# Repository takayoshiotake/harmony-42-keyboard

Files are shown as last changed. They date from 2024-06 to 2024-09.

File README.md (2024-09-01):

# Harmony 42

[][cc-by-sa]
[][freecad]
[][inkscape]
[][kicad]
[][vial]

A 42-key keyboard.

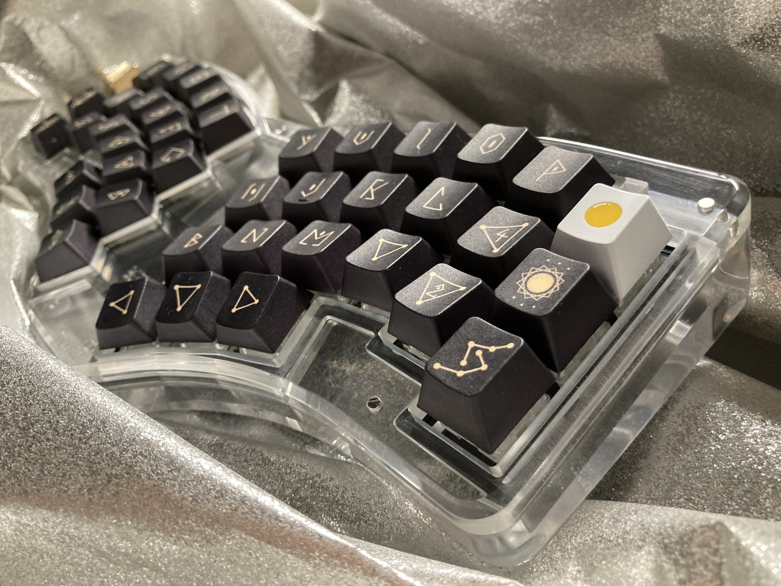
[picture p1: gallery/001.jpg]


- Switch: TTC Frozen V2
- Keycap: StarryPoem + HIBI Artisan

## Concept



## Layout

v0.1.0

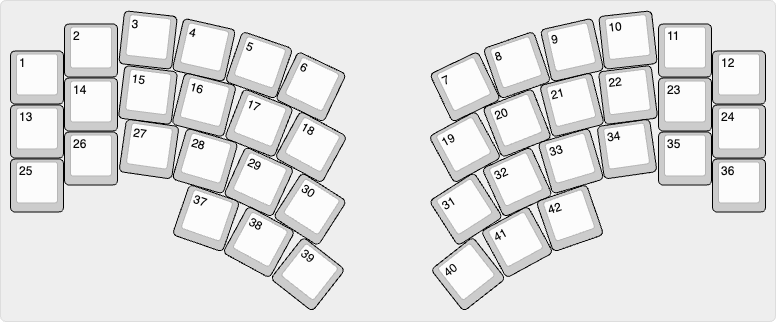
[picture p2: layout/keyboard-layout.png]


- width: 14u
- depth: <6u

Made with Python script: 📁 [editor](layout/editor)

- 📄 [locations.csv](layout/locations.csv)
- 📄 [keyboard-layout.rawdata.json](layout/keyboard-layout.rawdata.json)

## BOM

| Material | QTY | Note |
|-|-:|-|
| Harmony 42 PCB | 1 | [Schematic-and-PCB](#schematic-and-pcb) |
| MCU 16 PCB | 1 | [Schematic-and-PCB](#schematic-and-pcb) |
| Harmony 42 Case | 1 | PMMA CNC, [Mechanics](#mechanics) |
| Harmony 42 Gasket | 1 | PORON 2mm, [Mechanics](#mechanics) |
| Harmony 42 Plate | 1 | Acrylic 1.5mm, [Mechanics](#mechanics) |
| FFC | 1 | 16 ciruits, 0.50mm pitch, Type D (opposite sides), >50mm length |
| Screw: M2 x 4mm | 5 | |

## Schematic and PCB

schematic svg

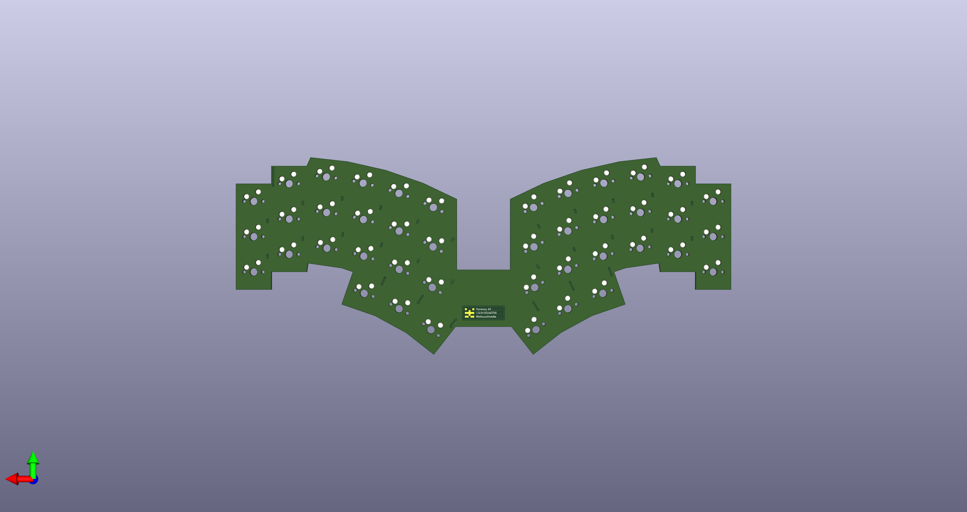
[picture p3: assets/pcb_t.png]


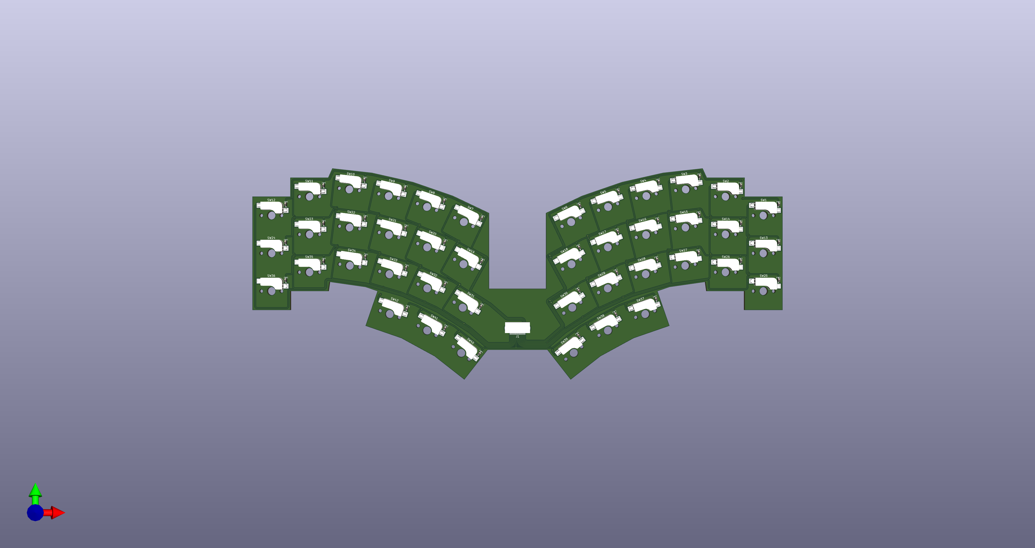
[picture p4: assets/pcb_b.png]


schematic svg

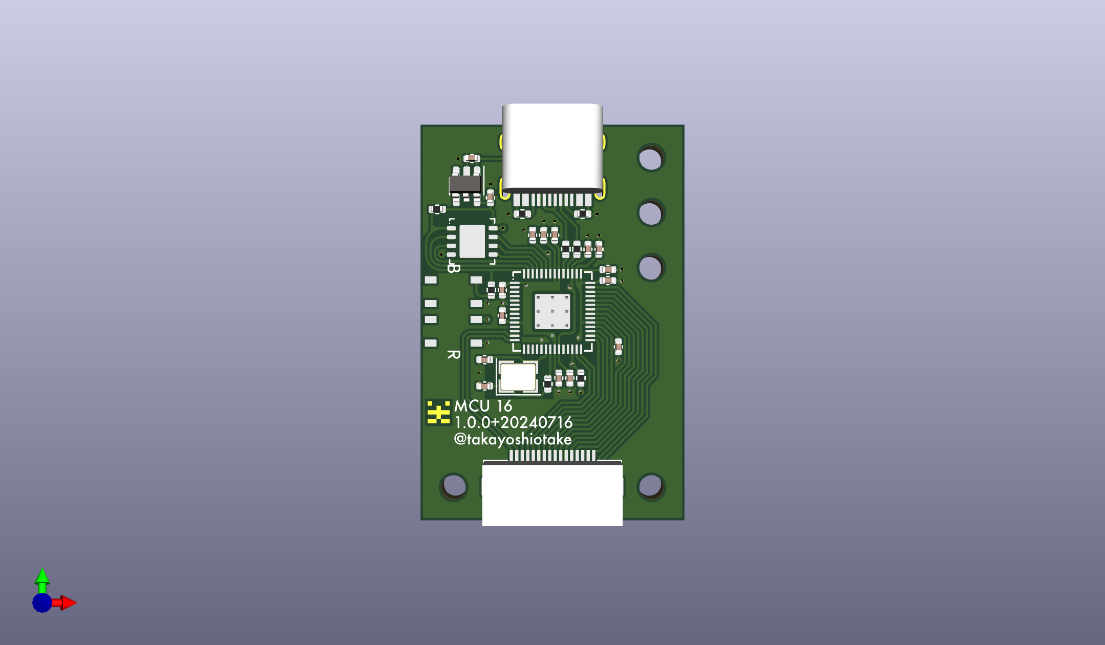
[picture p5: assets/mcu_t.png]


KiCad files:

- 📄 [harmony-42-pcb.kicad_sch](electronics/harmony-42-pcb/harmony-42-pcb.kicad_sch) (v1.0.0)
- 📄 [harmony-42-pcb.kicad_pcb](electronics/harmony-42-pcb/harmony-42-pcb.kicad_pcb) (v1.0.0)
- 📄 [mcu-16-pcb.kicad_sch](electronics/mcu-16-pcb/mcu-16-pcb.kicad_sch) (v1.0.0)
- 📄 [mcu-16-pcb.kicad_pcb](electronics/mcu-16-pcb/mcu-16-pcb.kicad_pcb) (v1.0.0)

## Mechanics

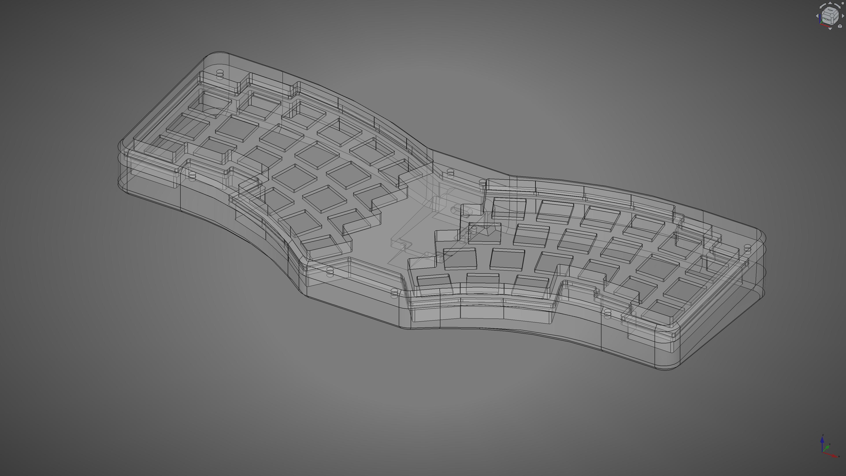
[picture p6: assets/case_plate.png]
topview svg


Files:

- 📄 [harmony-42-case-topview.svg](mechanics/harmony-42-case-topview.svg)
    - 📄 [1.5mm PMMA plate for 遊舎工房 レーザー加工サービス](mechanics/harmony-42-plate_Laser_A4_template_inkscape.svg)
        - アクリル クリア 1.5mm A4
    - 📄 [2mm PORON gasket for 遊舎工房 レーザー加工サービス](mechanics/harmony-42-gasket_Poron%20laserCut%20Template%202022-10-20_OUTLINED.svg)
        - フォーム 2mm 297x190接着シート付き
- 📄 [harmony-42-case.FCStd](mechanics/harmony-42-case.FCStd)
    - 📄 [harmony-42-case-Top.step](mechanics/harmony-42-case-Top.step)
    - 📄 [harmony-42-case-Bottom.step](mechanics/harmony-42-case-Bottom.step)

## Firmware

### Vial

- Built UF2
    - 📄 [takayoshiotake_harmony_42_vial_20240726.uf2](vial-bin/takayoshiotake_harmony_42_vial_20240726.uf2)
- Code
    - 🔗 <https://github.com/vial-kb/vial-qmk/tree/vial/keyboards/takayoshiotake/harmony_42>

See [vial-porting](vial-porting) for more details.

## License

This work is licensed under a
[Creative Commons Attribution-ShareAlike 4.0 International License][cc-by-sa].

[][cc-by-sa]

[cc-by-sa]: http://creativecommons.org/licenses/by-sa/4.0/
[cc-by-sa-image]: https://licensebuttons.net/l/by-sa/4.0/88x31.png
[cc-by-sa-shield]: https://img.shields.io/badge/license-CC%20BY--SA%204.0-lightgrey.svg

[freecad]: https://www.freecad.org/
[freecad-shield]: https://img.shields.io/badge/FreeCAD-gray.svg?logo=freecad

[inkscape]: https://inkscape.org/
[inkscape-shield]: https://img.shields.io/badge/Inkscape-gray.svg?logo=inkscape&logoColor=000000

[kicad]: https://www.kicad.org/
[kicad-shield]: https://img.shields.io/badge/KiCad-314CB0.svg

[vial]: https://get.vial.today/
[vial-shield]: https://img.shields.io/badge/Vial-03045E.svg

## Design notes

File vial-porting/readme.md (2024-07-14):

# Harmony 42

Harmony 42

Vial firmware for the Harmony 42 (40%) keyboard. You can find other information including hardware design in the [GitHub repository](https://github.com/takayoshiotake/harmony-42-keyboard).

Keyboard Maintainer: [takayoshiotake](https://github.com/takayoshiotake)

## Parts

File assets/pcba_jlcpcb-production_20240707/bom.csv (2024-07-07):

Designator | Footprint | Quantity | Value | LCSC Part #
D1, D10, D11, D12, D13, D14, D15, D16, D17, D18, D19, D2, D20, D21, D22, D23, D24, D25, D26, D27, D28, D29, D3, D30, D31, D32, D33, D34, D35, D36, D37, D38, D39, D4, D40, D41, D42, D5, D6, D7, D8, D9 | D_SOD-323F | 42 | 1N4148WS | C2128
J1 | JUSHUO_AFC01-S16FCC-00 | 1 | FFC Connector | C262272
SW1, SW10, SW11, SW12, SW13, SW14, SW15, SW16, SW17, SW18, SW19, SW2, SW20, SW21, SW22, SW23, SW24, SW25, SW26, SW27, SW28, SW29, SW3, SW30, SW31, SW32, SW33, SW34, SW35, SW36, SW37, SW38, SW39, SW4, SW40, SW41, SW42, SW5, SW6, SW7, SW8, SW9 | Hot_Swap_Socket_CPG151101S11 | 42 | ~ | C5156480

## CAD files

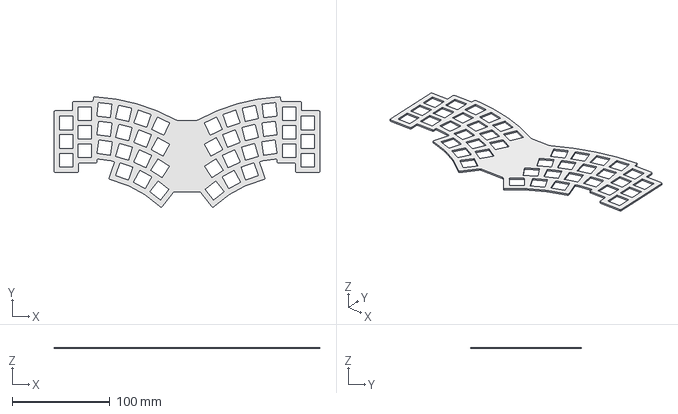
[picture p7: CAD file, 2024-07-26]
mechanics/harmony-42-plate.step
272.7 x 113.3 x 1.50 mm

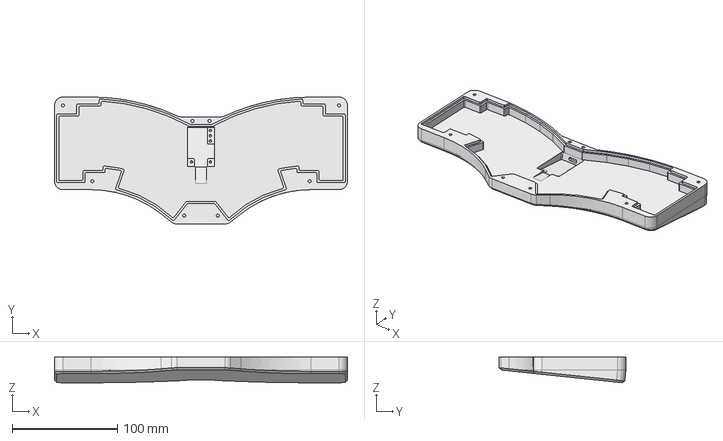
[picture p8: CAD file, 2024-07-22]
mechanics/harmony-42-case-Bottom.step
278.9 x 120.9 x 24.4 mm

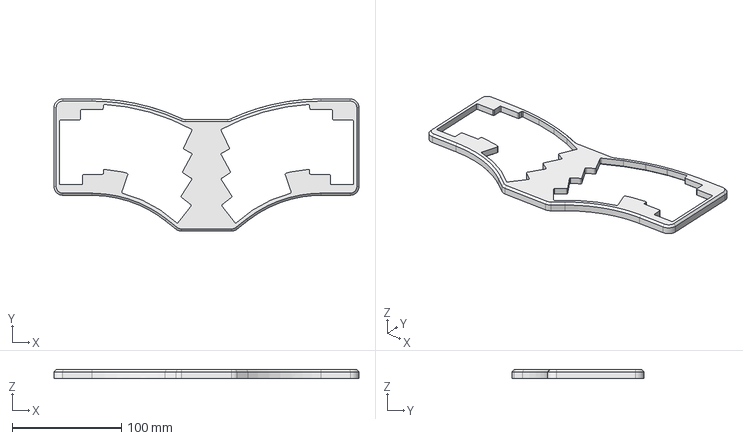
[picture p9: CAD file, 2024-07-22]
mechanics/harmony-42-case-Top.step
278.9 x 120.9 x 8.00 mm

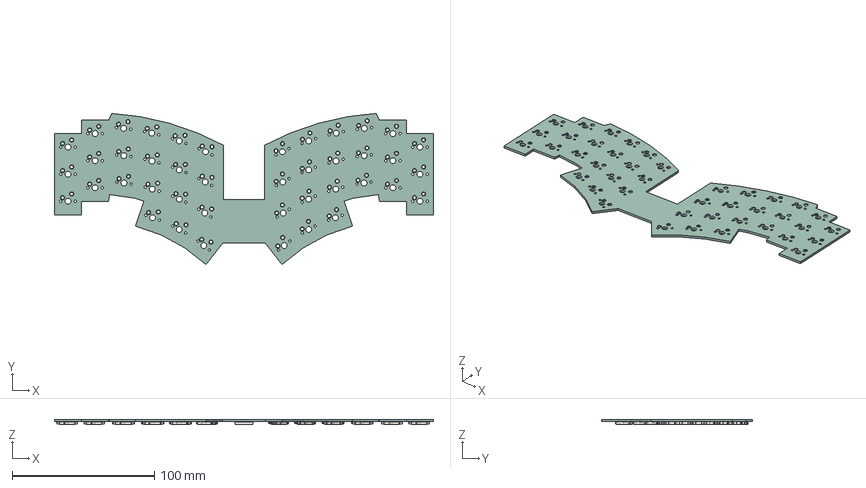
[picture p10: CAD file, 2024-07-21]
mechanics/harmony-42-pcb.step
266.7 x 106.3 x 3.65 mm
Hot_Swap_Socket_CPG151101S11 x 42
D_SOD_323 x 42
harmony-42-pcb_PCB

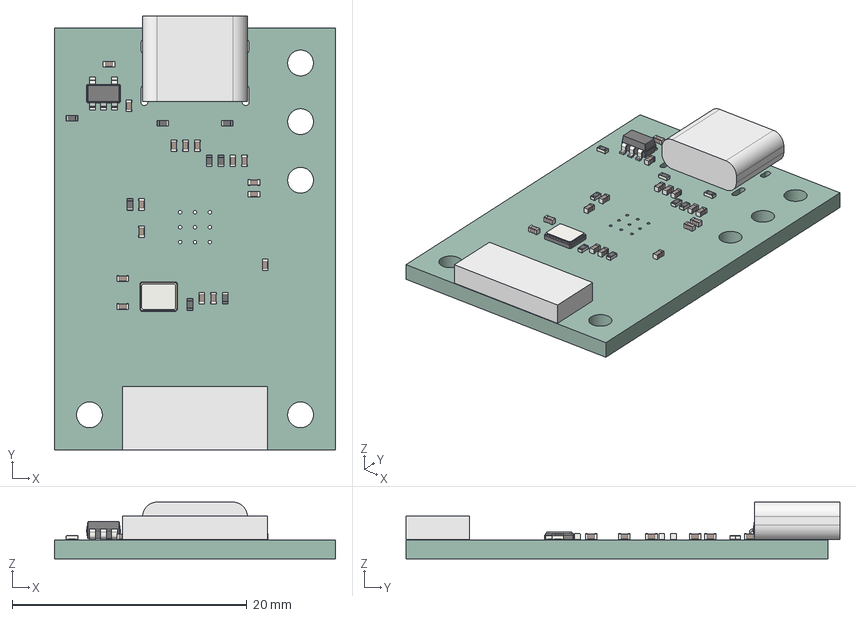
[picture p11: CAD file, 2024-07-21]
mechanics/mcu-16-pcb.step
24.0 x 37.0 x 4.85 mm
C_0402_1005Metric x 16
R_0402_1005Metric x 8
Crystal_SMD_3225-4Pin_3.2x2.5mm
SOT_23_5
mcu-16-pcb_PCB

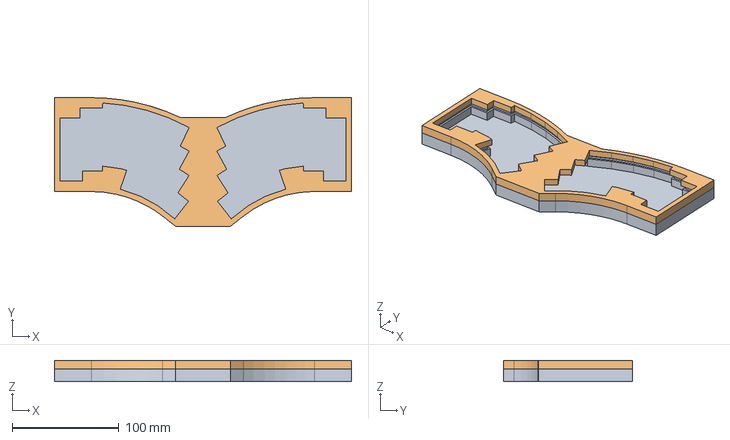
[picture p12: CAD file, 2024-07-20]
mechanics/harmony-42-case.FCStd
278.9 x 120.9 x 20.0 mm
Bottom
Top

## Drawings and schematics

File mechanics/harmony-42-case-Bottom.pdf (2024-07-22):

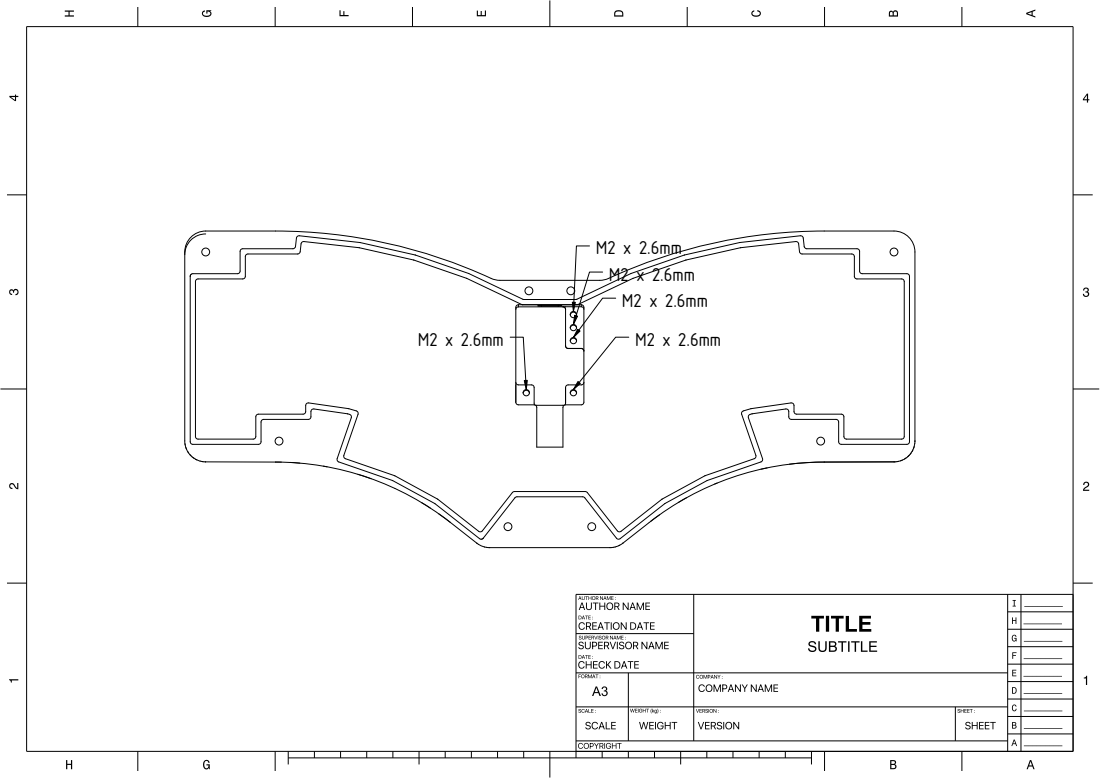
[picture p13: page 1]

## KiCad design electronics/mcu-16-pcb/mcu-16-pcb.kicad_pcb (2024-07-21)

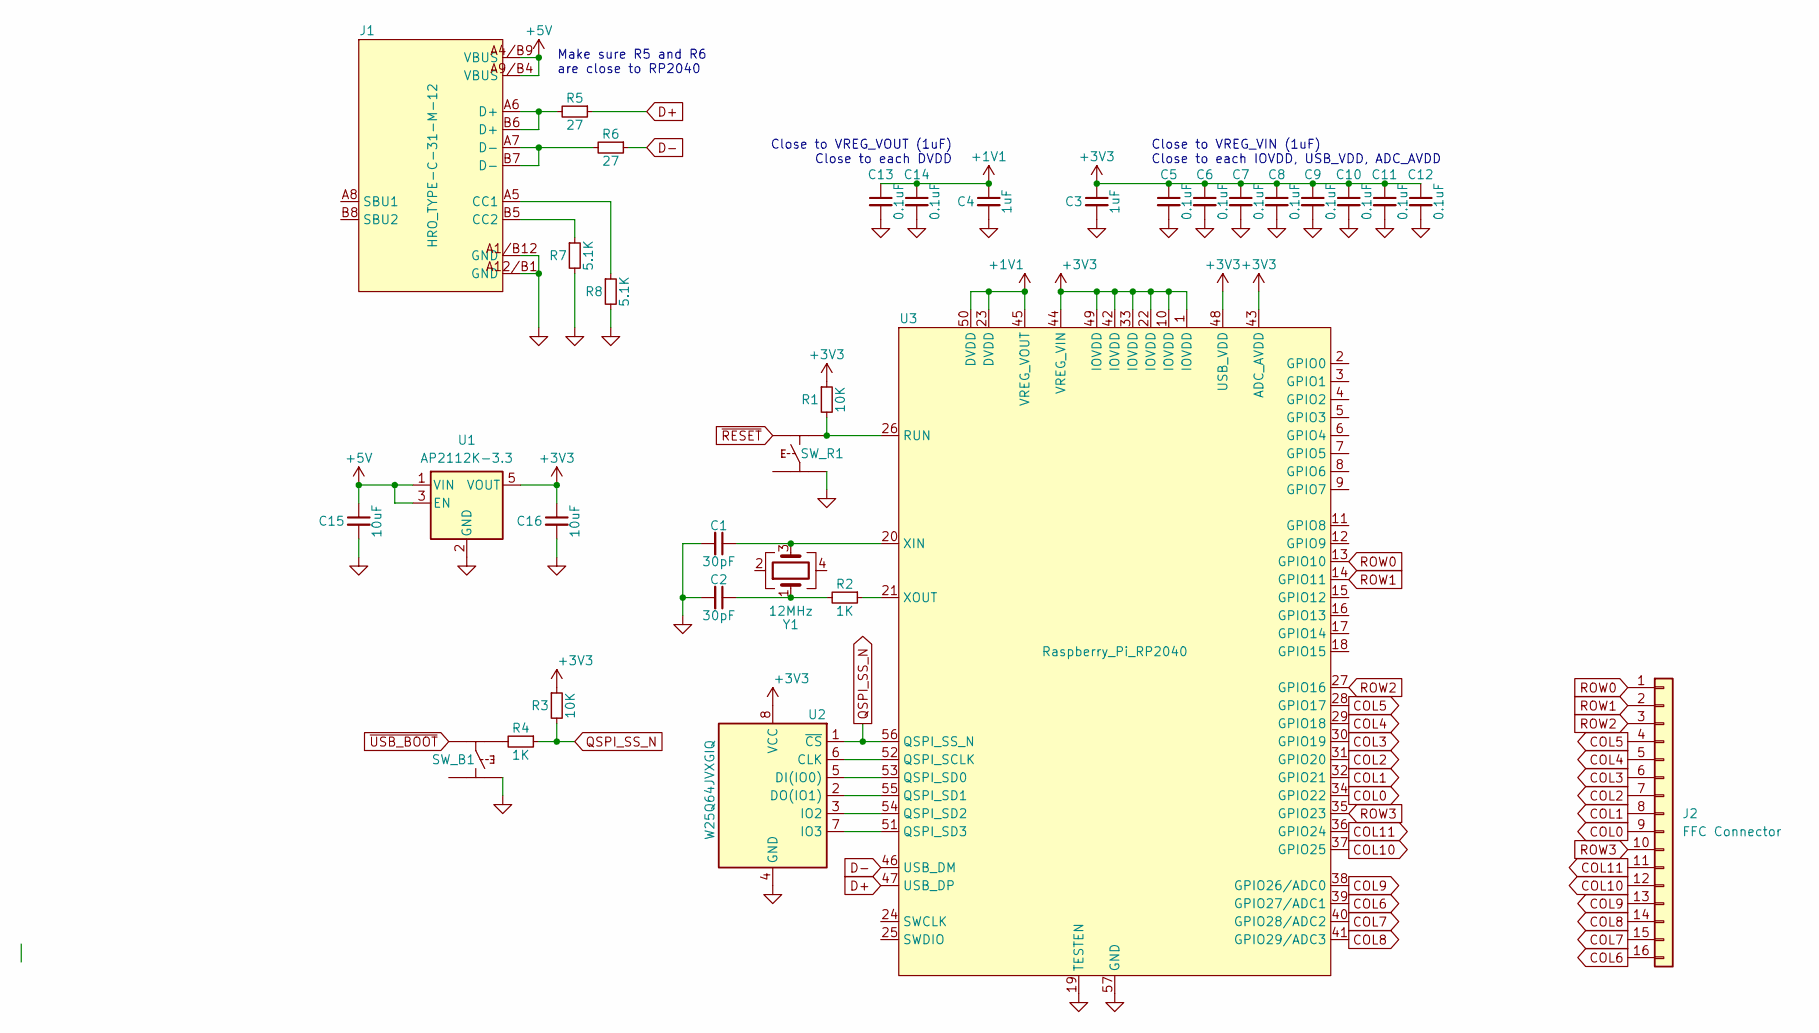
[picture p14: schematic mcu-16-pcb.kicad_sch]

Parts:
C1, C2: 30pF; C_0402_1005Metric; LCSC C1570
C3, C4: 1uF; C_0402_1005Metric; LCSC C52923
C5, C6, C7, C8, C9, C10, C11, C12, C13, C14: 0.1uF; C_0402_1005Metric; LCSC C307331
C15, C16: 10uF; C_0402_1005Metric; LCSC C15525
J1: HRO_TYPE-C-31-M-12; LCSC C165948
J2: FFC Connector; JUSHUO_AFC01-S16FCC-00; LCSC C262272
R1, R3: 10K; R_0402_1005Metric; LCSC C25744
R2, R4: 1K; R_0402_1005Metric; LCSC C11702
R5, R6: 27; R_0402_1005Metric; LCSC C25100
R7, R8: 5.1K; R_0402_1005Metric; LCSC C25905
SW_B1: Alps_Alpine_SKRP; Tactile_Switch_SKRP_Series; LCSC C115360
SW_R1: Alps_Alpine_SKRP; Tactile_Switch_SKRP_Series; LCSC C115360
U1: AP2112K-3.3; SOT-23-5; LCSC C51118
U2: W25Q64JVXGIQ; XSON-8-EP_4x4mm; LCSC C2940195
U3: Raspberry_Pi_RP2040; RP2040_QFN-56; LCSC C2040
Y1: 12MHz; Crystal_SMD_3225-4Pin_3.2x2.5mm; LCSC C9002

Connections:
+1V1: C4.1, C13.1, C14.1, U3.23 (DVDD), U3.45 (VREG_VOUT), U3.50 (DVDD)
+3V3: C3.1, C5.1, C6.1, C7.1, C8.1, C9.1, C10.1, C11.1, C12.1, C16.1, R1.1, R3.1, U1.5 (VOUT), U2.8 (VCC), U3.1 (IOVDD), U3.10 (IOVDD), U3.22 (IOVDD), U3.33 (IOVDD), U3.42 (IOVDD), U3.43 (ADC_AVDD), U3.44 (VREG_VIN), U3.48 (USB_VDD), U3.49 (IOVDD)
+5V: C15.1, J1.A4/B9 (VBUS), J1.A9/B4 (VBUS), U1.1 (VIN), U1.3 (EN)
COL0: J2.9, U3.34 (GPIO22)
COL1: J2.8, U3.32 (GPIO21)
COL2: J2.7, U3.31 (GPIO20)
COL3: J2.6, U3.30 (GPIO19)
COL4: J2.5, U3.29 (GPIO18)
COL5: J2.4, U3.28 (GPIO17)
COL6: J2.16, U3.39 (GPIO27/ADC1)
COL7: J2.15, U3.40 (GPIO28/ADC2)
COL8: J2.14, U3.41 (GPIO29/ADC3)
COL9: J2.13, U3.38 (GPIO26/ADC0)
COL10: J2.12, U3.37 (GPIO25)
COL11: J2.11, U3.36 (GPIO24)
D+: R5.1, U3.47 (USB_DP)
D-: R6.1, U3.46 (USB_DM)
GND: C1.2, C2.2, C3.2, C4.2, C5.2, C6.2, C7.2, C8.2, C9.2, C10.2, C11.2, C12.2, C13.2, C14.2, C15.2, C16.2, J1.A1/B12 (GND), J1.A12/B1 (GND), R7.2, R8.2, SW_B1.4, SW_R1.1, U1.2 (GND), U2.4 (GND), U3.19 (TESTEN), U3.57 (GND)
unnamed: C2.1, R2.2, Y1.1
unnamed: J1.A5 (CC1), R8.1
unnamed: J1.B5 (CC2), R7.1
unnamed: J1.A6 (D+), J1.B6 (D+), R5.2
unnamed: J1.A7 (D-), J1.B7 (D-), R6.2
unnamed: R4.2, SW_B1.2
unnamed: U2.6 (CLK), U3.52 (QSPI_SCLK)
unnamed: U2.5 (DI(IO0)), U3.53 (QSPI_SD0)
unnamed: U2.2 (DO(IO1)), U3.55 (QSPI_SD1)
unnamed: U2.3 (IO2), U3.54 (QSPI_SD2)
unnamed: U2.7 (IO3), U3.51 (QSPI_SD3)
unnamed: R1.2, SW_R1.3, U3.26 (RUN)
unnamed: C1.1, U3.20 (XIN), Y1.3
unnamed: R2.1, U3.21 (XOUT)
QSPI_SS_N: R3.2, R4.1, U2.1 (~CS), U3.56 (QSPI_SS_N)
ROW0: J2.1, U3.13 (GPIO10)
ROW1: J2.2, U3.14 (GPIO11)
ROW2: J2.3, U3.27 (GPIO16)
ROW3: J2.10, U3.35 (GPIO23)
~RESET: SW_R1.4
~USB_BOOT: SW_B1.1

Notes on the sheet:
Close to VREG_VIN (1uF) Close to each IOVDD, USB_VDD, ADC_AVDD
Close to VREG_VOUT (1uF) Close to each DVDD
Make sure R5 and R6 are close to RP2040

Board: 2 copper layers, 32 parts (0 on the bottom side), 37 nets, no tracks yet.

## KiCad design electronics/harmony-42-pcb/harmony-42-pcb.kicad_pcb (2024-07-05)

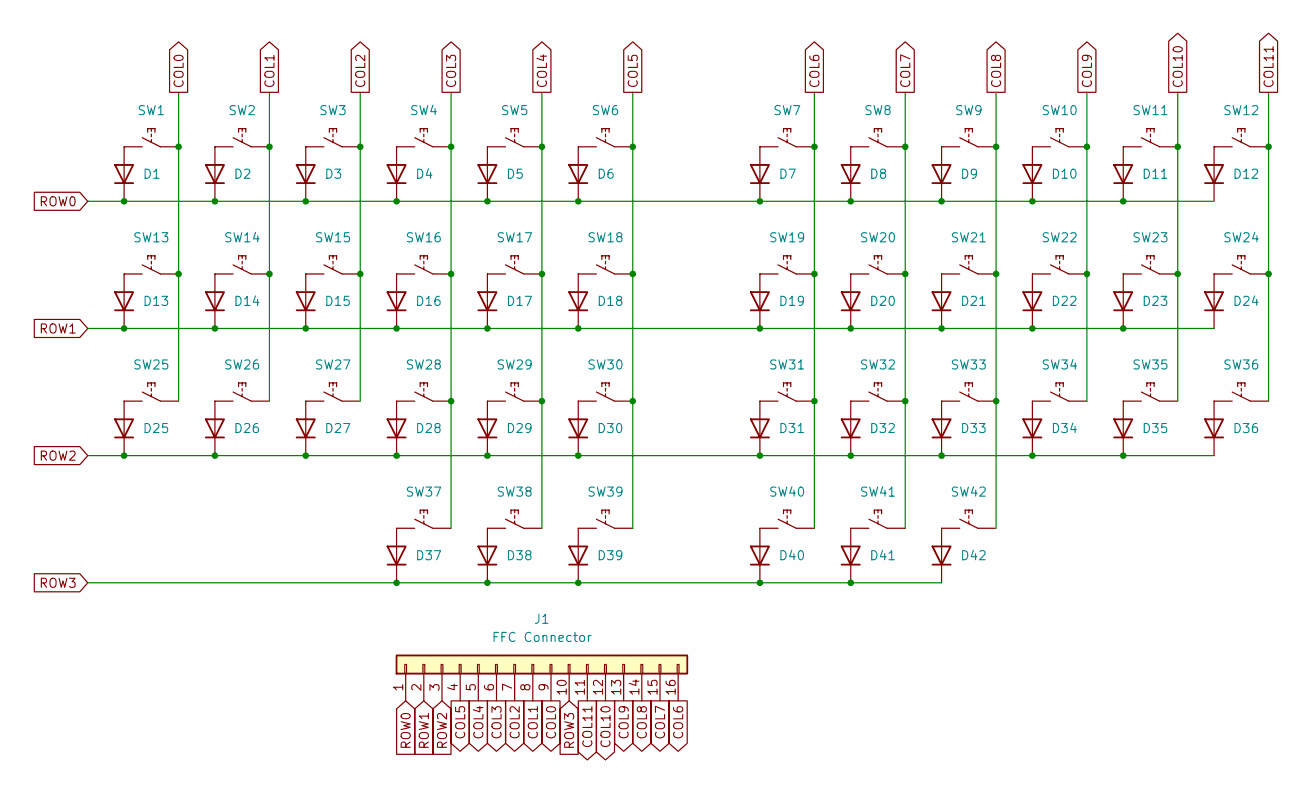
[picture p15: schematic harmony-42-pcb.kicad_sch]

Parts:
D1, D2, D3, D4, D5, D6, D7, D8, D9, D10, D11, D12, D13, D14, D15, D16, D17, D18, D19, D20, D21, D22, D23, D24, D25, D26, D27, D28, D29, D30, D31, D32, D33, D34, D35, D36, D37, D38, D39, D40, D41, D42: 1N4148WS; D_SOD-323F; LCSC C2128
J1: FFC Connector; JUSHUO_AFC01-S16FCC-00; LCSC C262272
SW1, SW2, SW3, SW4, SW5, SW6, SW7, SW8, SW9, SW10, SW11, SW12, SW13, SW14, SW15, SW16, SW17, SW18, SW19, SW20, SW21, SW22, SW23, SW24, SW25, SW26, SW27, SW28, SW29, SW30, SW31, SW32, SW33, SW34, SW35, SW36, SW37, SW38, SW39, SW40, SW41, SW42: Hot_Swap_Socket_CPG151101S11; LCSC C5156480

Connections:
COL0: J1.9, SW1.1, SW13.1, SW25.1
COL1: J1.8, SW2.1, SW14.1, SW26.1
COL2: J1.7, SW3.1, SW15.1, SW27.1
COL3: J1.6, SW4.1, SW16.1, SW28.1, SW37.1
COL4: J1.5, SW5.1, SW17.1, SW29.1, SW38.1
COL5: J1.4, SW6.1, SW18.1, SW30.1, SW39.1
COL6: J1.16, SW7.1, SW19.1, SW31.1, SW40.1
COL7: J1.15, SW8.1, SW20.1, SW32.1, SW41.1
COL8: J1.14, SW9.1, SW21.1, SW33.1, SW42.1
COL9: J1.13, SW10.1, SW22.1, SW34.1
COL10: J1.12, SW11.1, SW23.1, SW35.1
COL11: J1.11, SW12.1, SW24.1, SW36.1
unnamed: D1.2 (A), SW1.2
unnamed: D2.2 (A), SW2.2
unnamed: D3.2 (A), SW3.2
unnamed: D4.2 (A), SW4.2
unnamed: D5.2 (A), SW5.2
unnamed: D6.2 (A), SW6.2
unnamed: D7.2 (A), SW7.2
unnamed: D8.2 (A), SW8.2
unnamed: D9.2 (A), SW9.2
unnamed: D10.2 (A), SW10.2
unnamed: D11.2 (A), SW11.2
unnamed: D12.2 (A), SW12.2
unnamed: D13.2 (A), SW13.2
unnamed: D14.2 (A), SW14.2
unnamed: D15.2 (A), SW15.2
unnamed: D16.2 (A), SW16.2
unnamed: D17.2 (A), SW17.2
unnamed: D18.2 (A), SW18.2
unnamed: D19.2 (A), SW19.2
unnamed: D20.2 (A), SW20.2
unnamed: D21.2 (A), SW21.2
unnamed: D22.2 (A), SW22.2
unnamed: D23.2 (A), SW23.2
unnamed: D24.2 (A), SW24.2
unnamed: D25.2 (A), SW25.2
unnamed: D26.2 (A), SW26.2
unnamed: D27.2 (A), SW27.2
unnamed: D28.2 (A), SW28.2
unnamed: D29.2 (A), SW29.2
unnamed: D30.2 (A), SW30.2
unnamed: D31.2 (A), SW31.2
unnamed: D32.2 (A), SW32.2
unnamed: D33.2 (A), SW33.2
unnamed: D34.2 (A), SW34.2
unnamed: D35.2 (A), SW35.2
unnamed: D36.2 (A), SW36.2
unnamed: D37.2 (A), SW37.2
unnamed: D38.2 (A), SW38.2
unnamed: D39.2 (A), SW39.2
unnamed: D40.2 (A), SW40.2
unnamed: D41.2 (A), SW41.2
unnamed: D42.2 (A), SW42.2
ROW0: D1.1 (K), D2.1 (K), D3.1 (K), D4.1 (K), D5.1 (K), D6.1 (K), D7.1 (K), D8.1 (K), D9.1 (K), D10.1 (K), D11.1 (K), D12.1 (K), J1.1
ROW1: D13.1 (K), D14.1 (K), D15.1 (K), D16.1 (K), D17.1 (K), D18.1 (K), D19.1 (K), D20.1 (K), D21.1 (K), D22.1 (K), D23.1 (K), D24.1 (K), J1.2
ROW2: D25.1 (K), D26.1 (K), D27.1 (K), D28.1 (K), D29.1 (K), D30.1 (K), D31.1 (K), D32.1 (K), D33.1 (K), D34.1 (K), D35.1 (K), D36.1 (K), J1.3
ROW3: D37.1 (K), D38.1 (K), D39.1 (K), D40.1 (K), D41.1 (K), D42.1 (K), J1.10

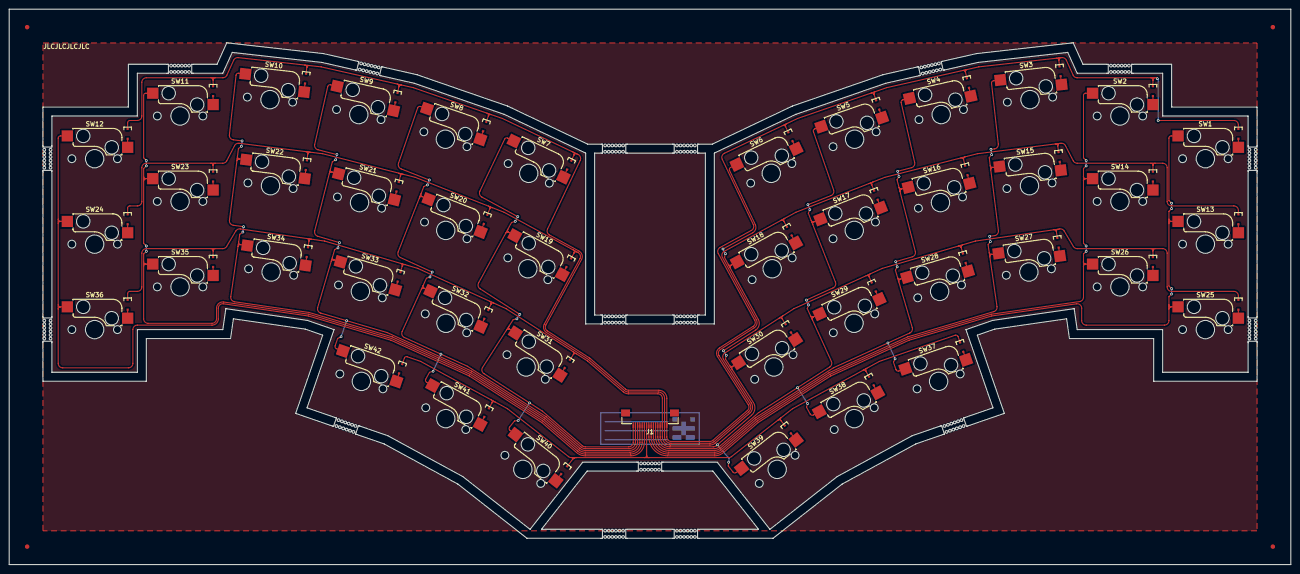
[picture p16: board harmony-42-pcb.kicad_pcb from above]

Board: 2 copper layers, 285.8 x 123.8 mm, 85 parts (0 on the bottom side), 58 nets.

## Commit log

2024-06-17 Add layout image
    The layout is made with Python scripts in the layout/editor.
    [locations.csv]
2024-06-18 Add kicad project for PCB
    [harmony-42-pcb.kicad_pcb, harmony-42-pcb.kicad_sch]
2024-06-18 Add keys
    [harmony-42-pcb.kicad_pcb, harmony-42-pcb.kicad_sch]
2024-06-18 Add diodes
    [harmony-42-pcb.kicad_pcb, harmony-42-pcb.kicad_sch]
2024-06-19 Fix mounting side of parts
    [harmony-42-pcb.kicad_pcb]
2024-06-22 Move diodes
    [harmony-42-pcb.kicad_pcb, harmony-42-pcb.kicad_sch]
2024-06-22 Route some sw
    [harmony-42-pcb.kicad_pcb]
2024-06-23 Add routes
    [harmony-42-pcb.kicad_pcb]
2024-06-24 Add routes for one side
    [harmony-42-pcb.kicad_pcb]
2024-06-24 Fix fillet radius
    [harmony-42-pcb.kicad_pcb]
2024-07-02 Change routes
    [harmony-42-pcb.kicad_pcb]
2024-07-05 Update pcb
    [harmony-42-pcb.kicad_pcb]
2024-07-07 Add production data
    [bom.csv, designators.csv, positions.csv]
2024-07-07 Add PCB images
2024-07-07 Move files
    [bom.csv, designators.csv, positions.csv]
2024-07-09 Add simple version PCB design
    [harmony-42-pcb_simple.kicad_pcb]
2024-07-14 Add mcu kicad project
    [mcu-16-pcb.kicad_pcb, mcu-16-pcb.kicad_sch]
2024-07-15 WIP Update
    [mcu-16-pcb.kicad_pcb, mcu-16-pcb.kicad_sch]
2024-07-15 Update MCU 16 pcb
    [mcu-16-pcb.kicad_pcb, mcu-16-pcb.kicad_sch]
2024-07-18 Add MCU 16 files
    [mcu-16-pcb.kicad_pcb, mcu-16-pcb.kicad_sch]
2024-07-18 Add kicad project for plate
    [harmony-42-plate.kicad_pcb]
2024-07-18 Add key locations data on PCB
    [locations-pcb.csv]
2024-07-21 Update case design
    [harmony-42-pcb.step, harmony-42-pcb_simple.step]
2024-07-21 Update MCU 16 position
    [mcu-16-pcb.step]
2024-07-21 Update case gap for poron
2024-07-21 Update gasket: poron 2mm
2024-07-22 Make 3d data
    [harmony-42-case-Bottom.step, harmony-42-case-Top.step]
2024-07-23 Add plate 3d data
    [harmony-42-plate.step]
2024-07-26 Update plate design
    [harmony-42-plate.step]
2024-08-16 Add case image
2024-09-01 Add BOM table

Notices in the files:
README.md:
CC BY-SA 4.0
